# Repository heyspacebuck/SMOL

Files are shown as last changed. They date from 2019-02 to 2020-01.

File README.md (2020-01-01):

# SMOL

## **S**lot-in **M**anipulator of **O**utput **L**evels

## (Revision 7)

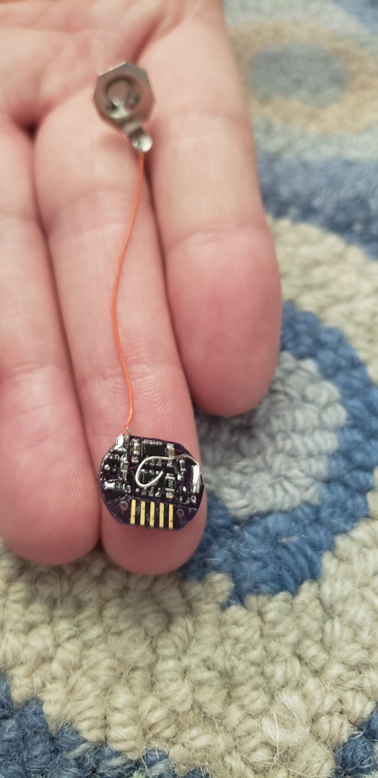
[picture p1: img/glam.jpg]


It's a little PCB to rapidly turn on/off any simple battery-powered circuits. An Atmel ATTiny drives an N-channel MOSFET, which selectively breaks or completes the circuit. The tiny form factor makes it super-simple to install in a battery-powered circuit. Just slot the board between the negative end of the battery and the spring contact, and run a single wire up to the positive battery terminal.

Even with its miniscule form factor, SMOL is designed to be built by surface-mount novices! It has friendly large SMD pads to accept 0603 or 0805 components, and relatively big IC packages (no pitch smaller than 0.90 mm).

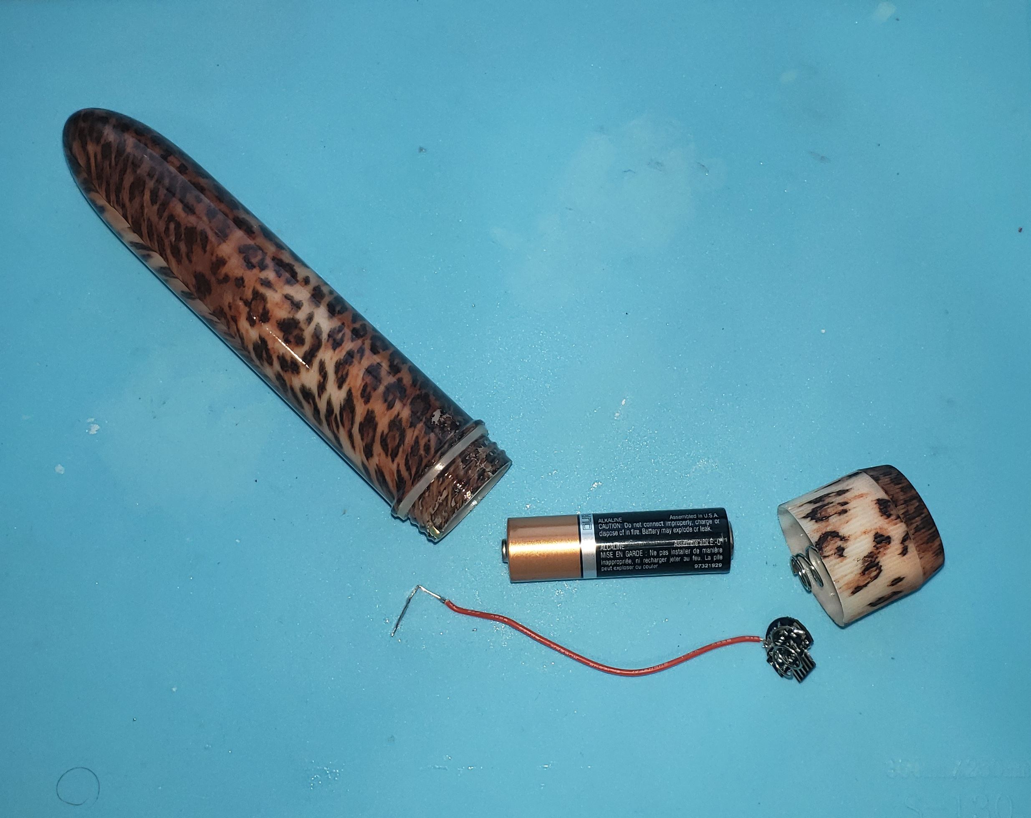
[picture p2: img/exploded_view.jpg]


If you want to contribute, please do! This thing is here for everyone to experiment with! The circuit is designed in KiCad, just clone/download it and open the project. The project includes self-contained parts and footprints libraries, so it *should* work on any KiCad 5 installation.

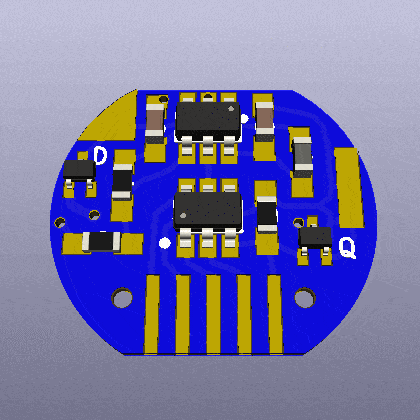
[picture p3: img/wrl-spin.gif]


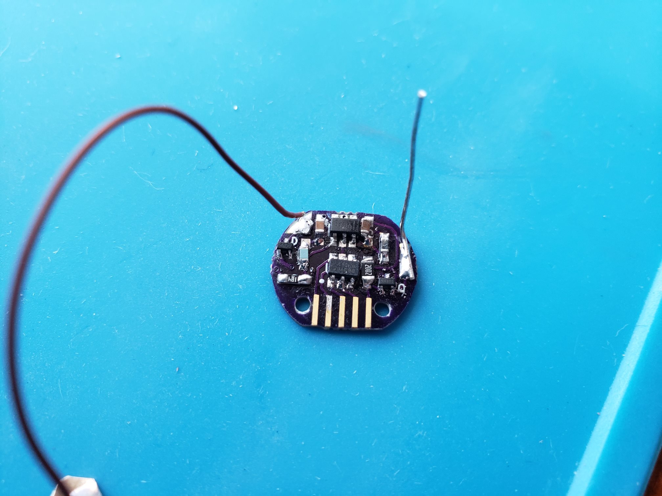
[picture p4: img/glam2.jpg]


## Programming the SMOL
That card-edge connector on the picture above is the [programming interface](programmer.md). Designing this part has been tougher than designing the actual SMOL! But once you get it working, you have the ATTiny10's entire kilobyte of program memory at your disposal. I suggest looking at the [example programs](Code%20examples/readme.md)

## Schematic
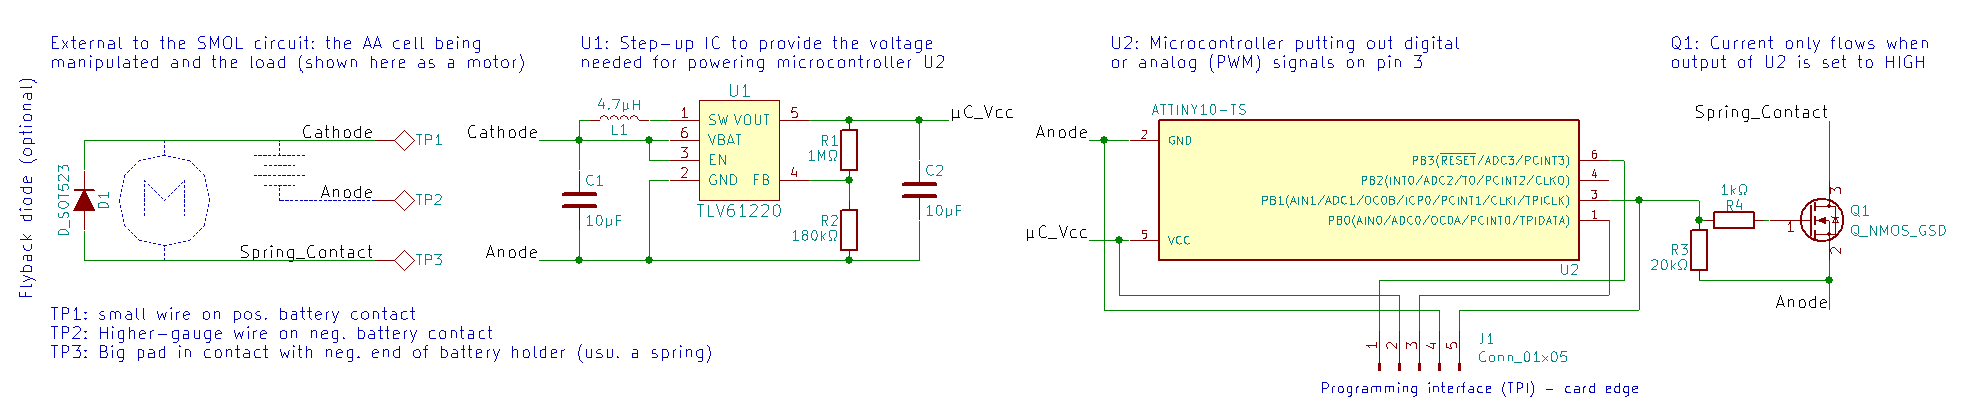
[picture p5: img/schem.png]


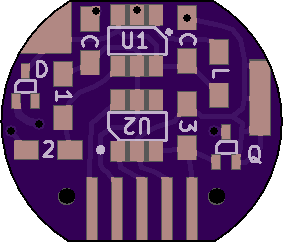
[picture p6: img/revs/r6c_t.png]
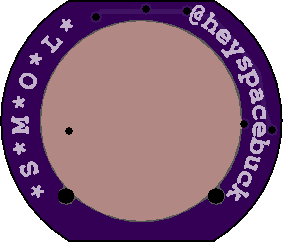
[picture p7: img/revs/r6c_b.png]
 

## Bill of Materials
| Designation | Description | My Source | My Cost (USD) | Notes |
|:---:|---|---|---|---|
| | Printed circuit board | JLCPCB | $0.125 | See the /gerbs/ folder |
| R1 | 1 MΩ resistor, SMD 0603 | [Digikey](https://www.digikey.com/product-detail/en/vishay-beyschlag/MCT06030C1004FP500/MCT0603-1.00M-CFCT-ND/2607877) | $0.180 | Abbreviated to "1" on the silkscreen. |
| R2 | 180 kΩ resistor, SMD 0603 | [Digikey](https://www.digikey.com/product-detail/en/yageo/RC0603FR-07180KL/311-180KHRCT-ND/729942) | $0.015 | Abbreviated to "2" on the silkscreen. |
| R3 | 20 kΩ resistor, SMD 0603  | [Digikey](https://www.digikey.com/product-detail/en/panasonic-electronic-components/ERJ-3EKF2002V/P20.0KHCT-ND/198237) | $0.100 | Abbreviated to "3" on the silkscreen. |
| R4 | 200 Ω resistor, SMD 0603  | [Digikey](https://www.digikey.com/product-detail/en/panasonic-electronic-components/ERJ-3EKF2000V/P200HCT-ND/198240) | $0.100 | Abbreviated to "4" on the silkscreen. |
| C1, C2 | 10 μF capacitor, SMD 0603 | [Digikey](https://www.digikey.com/product-detail/en/murata-electronics-north-america/ZRB18AR61C106ME01L/490-10990-1-ND/5321191) | $0.365 | Both are abbreviated to "C" on the silkscreen. |
| L1 | 4.7 μH inductor, SMD 0603 | [Digikey](https://www.digikey.com/product-detail/en/tdk-corporation/MLF1608A4R7KTA00/445-1021-1-ND/504419) | $0.200 | I should probably use one that's rated to more than 30 mA. Abbreviated to "L" on the silkscreen. |
| Q1 | N-channel MOSFET, SMD SOT-523 | [Digikey](https://www.digikey.com/product-detail/en/diodes-incorporated/DMG1012T-7/DMG1012T-7DICT-ND/2181232) | $0.360 | [Datasheet](https://www.diodes.com/assets/Datasheets/ds31783.pdf). Abbreviated to "Q" on the silkscreen. |
| D1 | General purpose diode, SMD SOT-523 | [Digikey](https://www.digikey.com/product-detail/en/micro-commercial-co/MMBD4448HT-TP/MMBD4448HT-TPMSCT-ND/2041561) | $0.270 | [Datasheet](http://www.mccsemi.com/up_pdf/MMBD4448HT_HTC_HTA_HTS%28SOT-523%29.pdf). This part is optional but protects the board from motor back-EMF. Abbreviated to "D" on the silkscreen. |
| U1 | TLV61220 DC-DC boost converter, SMD SOT-23-6 | [Digikey](https://www.digikey.com/product-detail/en/texas-instruments/TLV61220DBVR/296-30547-1-ND/3458120) | $0.900 | [Datasheet](http://www.ti.com/lit/ds/symlink/tlv61220.pdf) |
| U2 | ATTiny10 8-bit microcontroller, SMD SOT-23-6 Narrow | [Digikey](https://www.digikey.com/product-detail/en/microchip-technology/ATTINY10-TSHR/ATTINY10-TSHRCT-ND/2136158) | $0.340 | [Datasheet](http://ww1.microchip.com/downloads/en/DeviceDoc/Atmel-8127-AVR-8-bit-Microcontroller-ATtiny4-ATtiny5-ATtiny9-ATtiny10_Datasheet.pdf). Uses the TPI programming interface, which is a pain. |
| | Approx. 5 cm of 30AWG wire | Anywhere | $0.000 | Solder to TP1 and attach the other end to the battery's positive terminal. Soldering an old battery clip to the end helps make a reliable connection. |
| | Approx. 1 cm of stiff bare wire | Anywhere | $0.000 | Solder to TP2 and bend so the battery's negative terminal rests on it but doesn't short any traces. |
| | Conformal coating (or other insulating material) | Anywhere | $0.000 | Optional but recommended. Insulate the board so the stiff bare wire can't short anything. |

TOTAL COST PER BOARD: approx. $3.50

## Revision history
SMOL has changed a lot since I first got the idea. Amazingly, it hasn't gotten bigger. [For a commentated revision history: click here.](revisions.md)

## Contact info:
- E-mail heyspacebuck at gmail
- Twitter @heyspacebuck
- Telegram @spacebuck

## To Do:
- Write better assembly instructions
- Add pictures + video
- Post sample AVR code
- Add OSHW certification mark

------

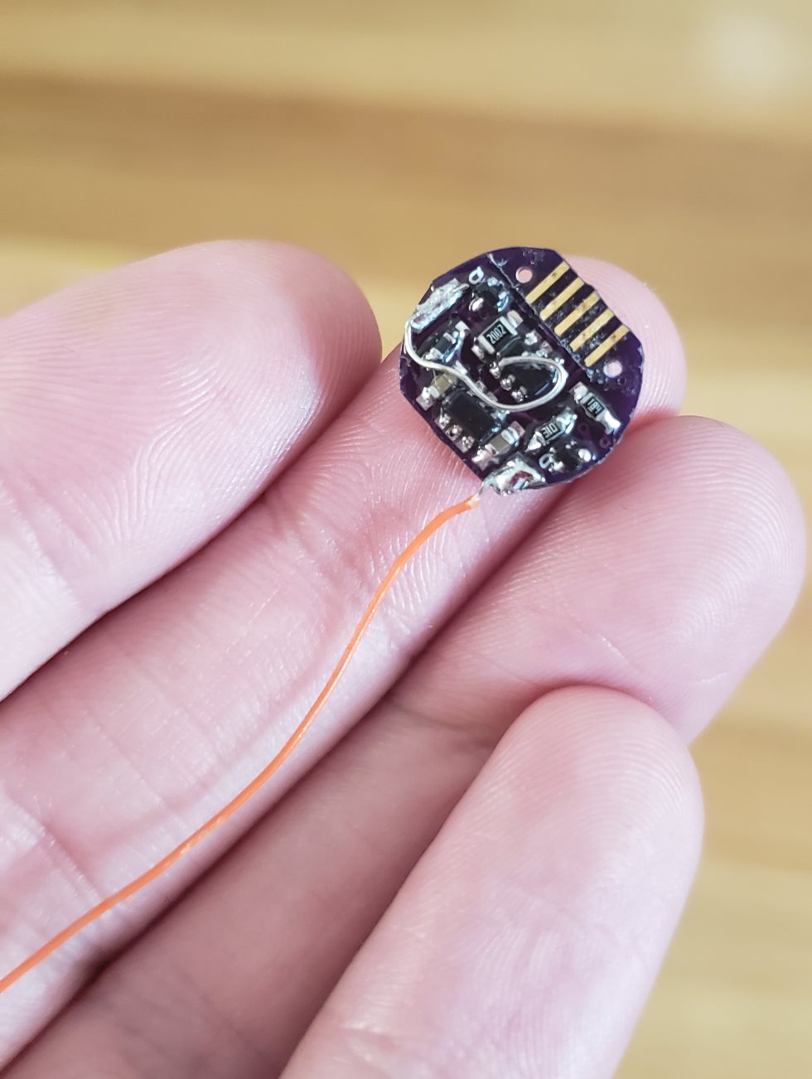
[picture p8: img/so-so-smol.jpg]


IT'S SO SMOL

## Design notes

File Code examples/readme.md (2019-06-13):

# Example AVR programs

I'm working on this section! The documentation is either flawed or absent altogether.

## 1. LED PWM pulse

This example pulses an LED with a PWM frequency of 312.5 Hz. It's overly complicated because it's based on the pomodoro timer, below.

## 2. Vibrator PWM pomodoro timer

The PWM rate in the previous example is 312.5 Hz. The coils of a motor would soak that up like a sponge! We need a faster PWM frequency if we're driving a motor, so that's what this example does.

## 3. Pseudorandom number generator

The ATTiny10 and ATTiny5 have an ADC which we can connect to PB0 (Pin 1, which on SMOL isn't connected to anything). By reading the least significant bit of the 8-bit analog reading, we get a fairly random result from environmental noise! Right now I'm just using this to set the motor on or off at one-second intervals.

## 4. Morse code "I Love You"

"If I had a little telegraph tapping in my brain / It would tap out Morse code 'I Love You'" --Devo, "The Words Get Stuck In My Throat" (Okay, so it's a cover of a song from _War of the Gargantuas_ but I only know it because of Booji Boy)

The Morse alphabet (A-Z, no numbers or punctuation yet) is included in `MorseAlphabet.cpp`. Simply change the functions called in the main .cpp file and you could spell out whatever you want!

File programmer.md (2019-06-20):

# Tiny Programming Interface (TPI) programmers for SMOL

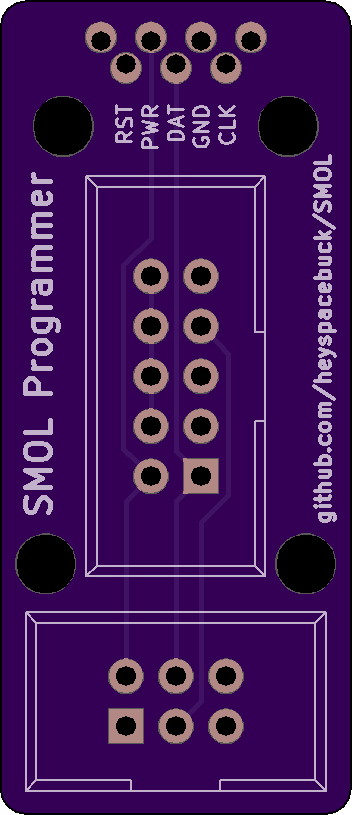
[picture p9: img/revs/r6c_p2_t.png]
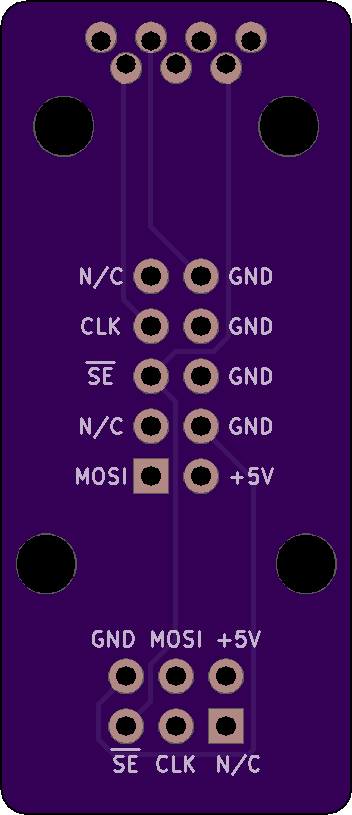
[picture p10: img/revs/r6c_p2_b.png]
 <br>
This design works with USBasp or a breadboard if you are using [this programming approach](http://www.technoblogy.com/show?1YQY).

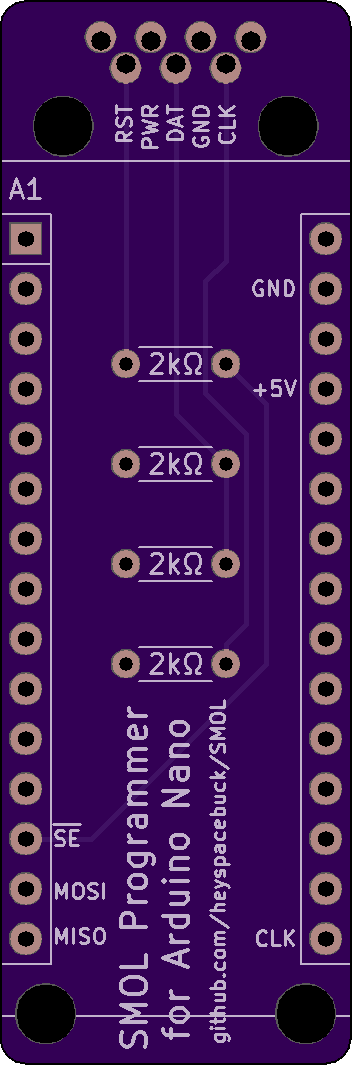
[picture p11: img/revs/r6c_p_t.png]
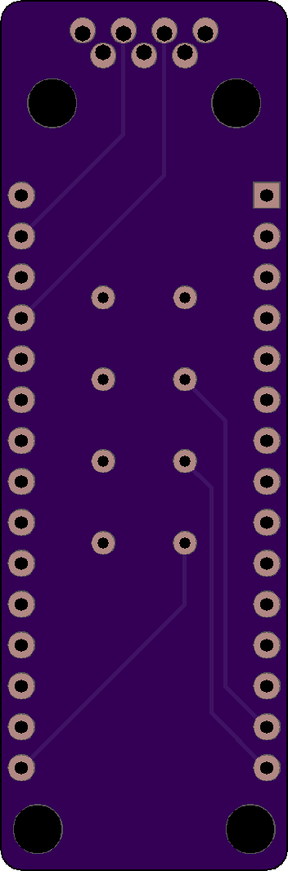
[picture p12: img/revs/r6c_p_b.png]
 <br>
This design works with the Arduino Nano (or breadboard) if you are using [this programming approach](http://junkplusarduino.blogspot.com/p/attiny10-resources.html).

The ATTiny10 at the heart of the SMOL can't be programmed like other ATTiny ICs. Instead of the normal 6-wire SPI (Serial Programming Interface) protocol, the ATTiny4/5/9/10 family use the 5-wire TPI (Tiny Programming Interface) protocol. Tutorials on working with TPI are relatively scarce. If you have a [Fischl USBasp](https://www.fischl.de/usbasp/) (or a knockoff that still supports low-clock-speed programming), you can write and upload your AVR program within the Arduino IDE by [following this landmark tutorial by Johnson Davies](http://www.technoblogy.com/show?1YQY). If you don't have USBasp, you can still upload compiled programs using this [very clever, very janky Arduino sketch](http://junkplusarduino.blogspot.com/p/attiny10-resources.html). Atmel Studio *should* work as an IDE but I haven't had any luck yet—contact me if you figure it out!

No matter what software you use, you'll need some additional hardware to connect your SMOL and your computer. On SMOL revision 7, the five TPI signals are routed to the five copper fingers, with a 50 mil (1.27 mm) pitch. There is a pair of non-plated through-holes (NPTH) to help align the programmer and the SMOL fingers.

## The least-bad programmer thus far

I'm using the classic [spring-loaded pogo pin](https://www.adafruit.com/product/2430) to make a reliable electrical connection between boards. These can be bought in bulk from lots of places—just make sure to get ones that are approx. 1mm diameter at their widest point.

The programmer has space for seven pogo pins: five signals and two alignment pins. The alignment pins should slide nicely into the 0.8mm diameter non-plated holes on SMOL, thereby forcing the five signal pins to accurately align themselves. The seven pogo pins are soldered into the programmer; be very careful on this step!

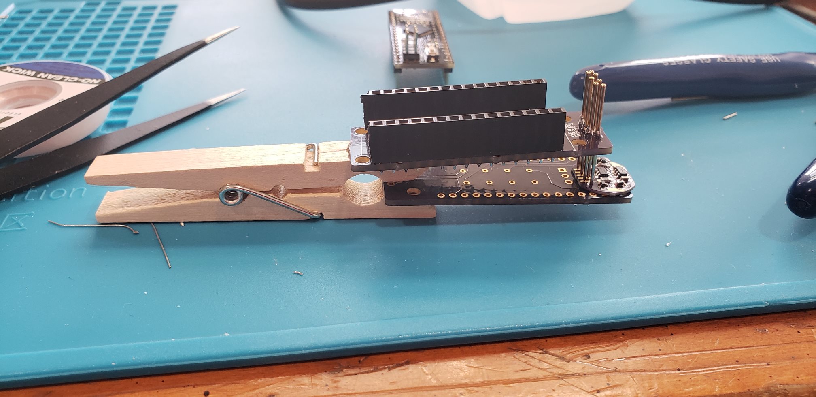
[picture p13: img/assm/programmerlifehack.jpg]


## Other attempts at SMOL programmers

My first programmers were wires soldered to bare pads. After that I tried programmers with mating fingers slid against the SMOL. This worked alright, but requires a lot of force to keep the programmer pressed against the SMOL, which started to take a toll on my poor fingertips:

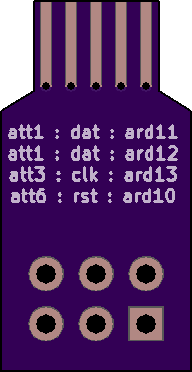
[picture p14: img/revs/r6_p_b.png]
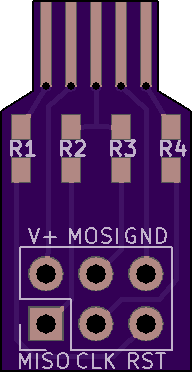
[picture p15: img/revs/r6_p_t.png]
 

In an attempt to work smarter, not harder, I made this sandwich programmer, which doesn't work well but is still my favorite design:

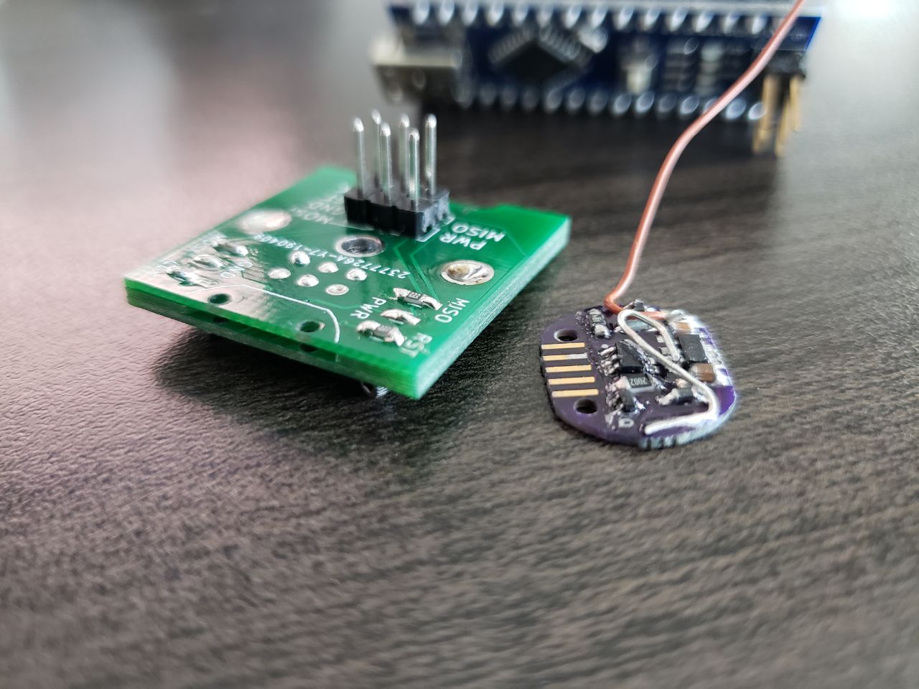
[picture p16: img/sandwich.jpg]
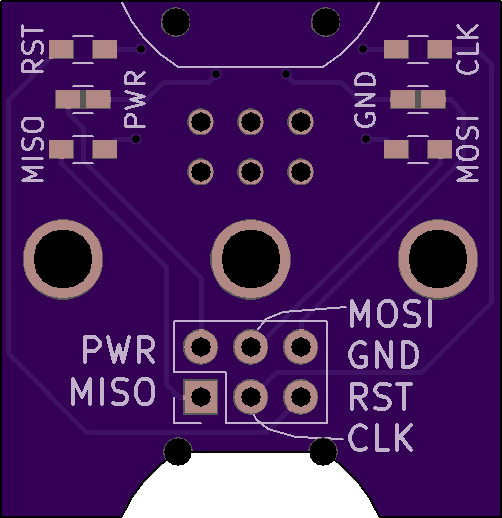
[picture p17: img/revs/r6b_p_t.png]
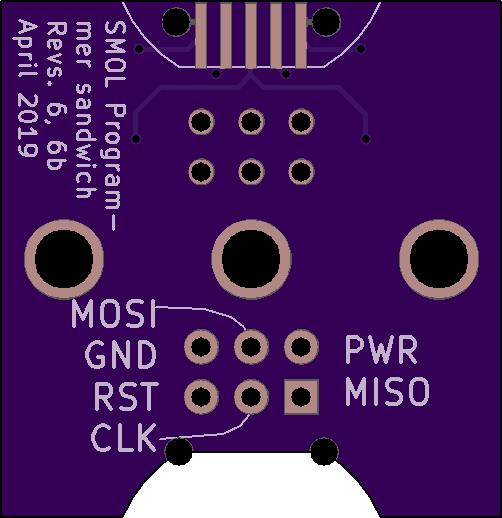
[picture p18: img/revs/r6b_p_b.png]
  

The middle PCB has a cutout to perfectly line up the SMOL, the top one has mating fingers, and the bottom one...well, I shouldn't have used a bottom PCB; I should have used some sort of spring apparatus to press the SMOL against the top fingers. In the 3-layer sandwich design, there's enough play that this programmer only works about 5% of the time. I still think this approach shows promise, but I can't figure out an economical way to make or buy card-edge receptacles for five fingers at 0.050" pitch.

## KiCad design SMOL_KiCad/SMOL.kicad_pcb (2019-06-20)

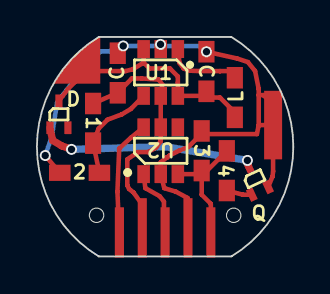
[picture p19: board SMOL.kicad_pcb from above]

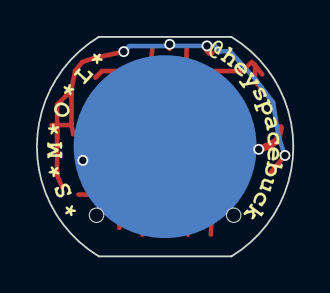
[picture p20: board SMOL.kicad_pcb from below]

Board: 2 copper layers, 14.2 x 12.2 mm, 19 parts (3 on the bottom side), 10 nets.

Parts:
1: 1MΩ; 0603_HandSoldering
2: 180kΩ; 0603_HandSoldering
3: 20kΩ; 0603_HandSoldering
4: 1kΩ; 0603_HandSoldering
C: 10μF; 0603_HandSoldering
C#2: 10μF; 0603_HandSoldering
D: D_SOT523; SOT523_HandSoldering
GFX1: credits2-name
GFX2: credits2-title
HOLE1, HOLE2: SolderWirePad_single_2mmDrill
J1: Conn_01x05; edgeconn
L: 4.7μH; 0603_HandSoldering
Q: Q_NMOS_GSD; SOT523_HandSoldering
TP1: TEST; Anchor_Pad
TP2: TEST; SPRING_ANCHOR
TP3: TEST; SPRING_LANDING
U1: TLV61220; SuperSOT-6
U2: ATTINY10-TS; SuperSOT-6

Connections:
/Anode: 2.2, 3.1, C.2, C#2.2, J1.4, Q.2, TP2.1, U1.2, U2.2
/Cathode: C.1, D.3, L.1, TP1.1, U1.3, U1.6
/Spring_Contact: D.1, Q.3, TP3.1
/μC_Vcc: 1.1, C#2.1, J1.2, U1.5, U2.5
unnamed: J1.1, U2.6
unnamed: J1.3, U2.1
unnamed: 3.2, 4.1, J1.5, U2.3
unnamed: L.2, U1.1
unnamed: 4.2, Q.1
unnamed: 1.2, 2.1, U1.4

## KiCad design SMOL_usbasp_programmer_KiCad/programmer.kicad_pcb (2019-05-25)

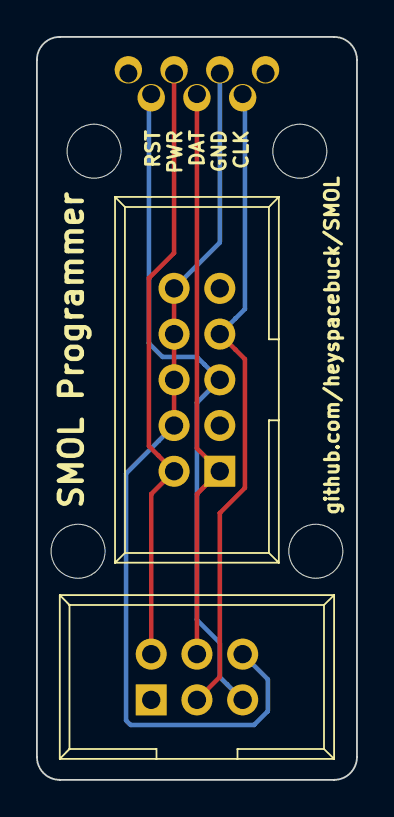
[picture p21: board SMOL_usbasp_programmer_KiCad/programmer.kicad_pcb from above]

Board: 2 copper layers, 17.8 x 41.3 mm, 9 parts (0 on the bottom side), 5 nets.

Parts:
CON1: AVR-TPI-6; IDC_Header_Straight_6pins
CON2: AVR-ISP-10; IDC_Header_Straight_10pins
HOLE1, HOLE2, HOLE3, HOLE4: MountingHole_3.2mm_M3
HOLE5, HOLE6: SolderWirePad_single_1mmDrill
J2: Conn_01x05; edgeconn

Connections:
/att_clk: CON1.3, CON2.7, J2.5
/att_data: CON1.4, CON2.1, J2.3
/att_reset: CON1.5, CON2.5, J2.1
/pwr: CON1.2, CON2.2, J2.2
GNDREF: CON1.6, CON2.4, CON2.6, CON2.8, CON2.10, J2.4

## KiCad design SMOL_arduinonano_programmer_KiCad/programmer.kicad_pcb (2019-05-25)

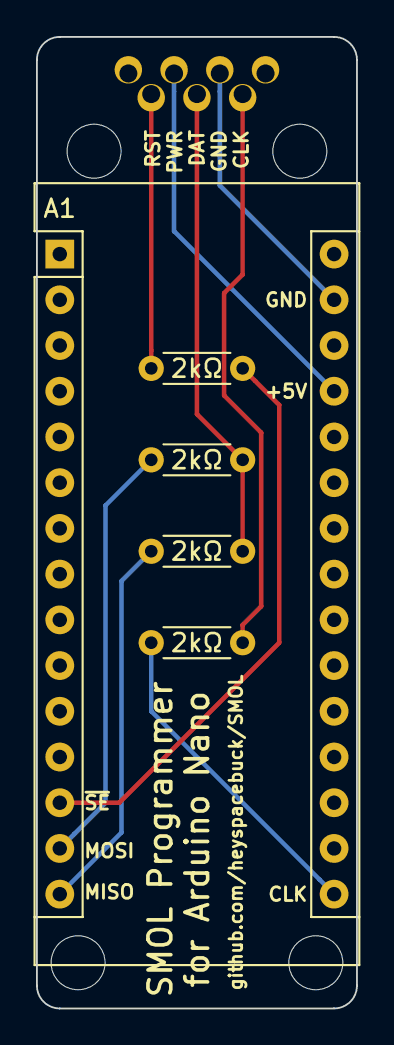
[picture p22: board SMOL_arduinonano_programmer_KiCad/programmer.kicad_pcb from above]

Board: 2 copper layers, 17.8 x 54.0 mm, 12 parts (0 on the bottom side), 9 nets.

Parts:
2kΩ, 2kΩ#2, 2kΩ#3, 2kΩ#4: 2k; R_Axial_DIN0204_L3.6mm_D1.6mm_P5.08mm_Horizontal
A1: Arduino_Nano_v3.x; Arduino_Nano
HOLE1, HOLE2, HOLE3, HOLE4: MountingHole_3.2mm_M3
HOLE5, HOLE6: SolderWirePad_single_1mmDrill
J2: Conn_01x05; edgeconn

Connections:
/att_clk: 2kΩ#4.2, J2.5
/att_data: 2kΩ#2.2, 2kΩ#3.2, J2.3
/att_reset: 2kΩ.2, J2.1
/prog_clk: 2kΩ#4.1, A1.16
/prog_miso: 2kΩ#2.1, A1.14
/prog_mosi: 2kΩ#3.1, A1.15
/prog_reset: 2kΩ.1, A1.13
/pwr: A1.27, J2.2
GNDREF: A1.4, A1.29, J2.4

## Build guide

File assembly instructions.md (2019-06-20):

# SMOL assembly instructions

Instructions are coming soon!

## Bill of Materials
| Designation | Description | My Source | My Cost (USD) | Notes |
|:---:|---|---|---|---|
| | Printed circuit board | JLCPCB | $0.125 | See the /gerbs/ folder |
| R1 | 1 MΩ resistor, SMD 0603 | [Digikey](https://www.digikey.com/product-detail/en/vishay-beyschlag/MCT06030C1004FP500/MCT0603-1.00M-CFCT-ND/2607877) | $0.180 | Abbreviated to "1" on the silkscreen. |
| R2 | 180 kΩ resistor, SMD 0603 | [Digikey](https://www.digikey.com/product-detail/en/yageo/RC0603FR-07180KL/311-180KHRCT-ND/729942) | $0.015 | Abbreviated to "2" on the silkscreen. |
| R3 | 20 kΩ resistor, SMD 0603  | [Digikey](https://www.digikey.com/product-detail/en/panasonic-electronic-components/ERJ-3EKF2002V/P20.0KHCT-ND/198237) | $0.100 | Abbreviated to "3" on the silkscreen. |
| R4 | 200 Ω resistor, SMD 0603  | [Digikey](https://www.digikey.com/product-detail/en/panasonic-electronic-components/ERJ-3EKF2000V/P200HCT-ND/198240) | $0.100 | Abbreviated to "4" on the silkscreen. |
| C1, C2 | 10 μF capacitor, SMD 0603 | [Digikey](https://www.digikey.com/product-detail/en/murata-electronics-north-america/ZRB18AR61C106ME01L/490-10990-1-ND/5321191) | $0.365 | Both are abbreviated to "C" on the silkscreen. |
| L1 | 4.7 μH inductor, SMD 0603 | [Digikey](https://www.digikey.com/product-detail/en/tdk-corporation/MLF1608A4R7KTA00/445-1021-1-ND/504419) | $0.200 | I should probably use one that's rated to more than 30 mA. Abbreviated to "L" on the silkscreen. |
| Q1 | N-channel MOSFET, SMD SOT-523 | [Digikey](https://www.digikey.com/product-detail/en/diodes-incorporated/DMG1012T-7/DMG1012T-7DICT-ND/2181232) | $0.360 | [Datasheet](https://www.diodes.com/assets/Datasheets/ds31783.pdf). Abbreviated to "Q" on the silkscreen. |
| D1 | General purpose diode, SMD SOT-523 | [Digikey](https://www.digikey.com/product-detail/en/micro-commercial-co/MMBD4448HT-TP/MMBD4448HT-TPMSCT-ND/2041561) | $0.270 | [Datasheet](http://www.mccsemi.com/up_pdf/MMBD4448HT_HTC_HTA_HTS%28SOT-523%29.pdf). This part is optional but protects the board from motor back-EMF. Abbreviated to "D" on the silkscreen. |
| U1 | TLV61220 DC-DC boost converter, SMD SOT-23-6 | [Digikey](https://www.digikey.com/product-detail/en/texas-instruments/TLV61220DBVR/296-30547-1-ND/3458120) | $0.900 | [Datasheet](http://www.ti.com/lit/ds/symlink/tlv61220.pdf) |
| U2 | ATTiny10 8-bit microcontroller, SMD SOT-23-6 Narrow | [Digikey](https://www.digikey.com/product-detail/en/microchip-technology/ATTINY10-TSHR/ATTINY10-TSHRCT-ND/2136158) | $0.340 | [Datasheet](http://ww1.microchip.com/downloads/en/DeviceDoc/Atmel-8127-AVR-8-bit-Microcontroller-ATtiny4-ATtiny5-ATtiny9-ATtiny10_Datasheet.pdf). Uses the TPI programming interface, which is a pain. |
| | Approx. 5 cm of 30AWG wire | Anywhere | $0.000 | Solder to TP1 and attach the other end to the battery's positive terminal. Soldering an old battery clip to the end helps make a reliable connection. |
| | Approx. 1 cm of stiff bare wire | Anywhere | $0.000 | Solder to TP2 and bend so the battery's negative terminal rests on it but doesn't short any traces. |
| | Conformal coating (or other insulating material) | Anywhere | $0.000 | Optional but recommended. Insulate the board so the stiff bare wire can't short anything. |

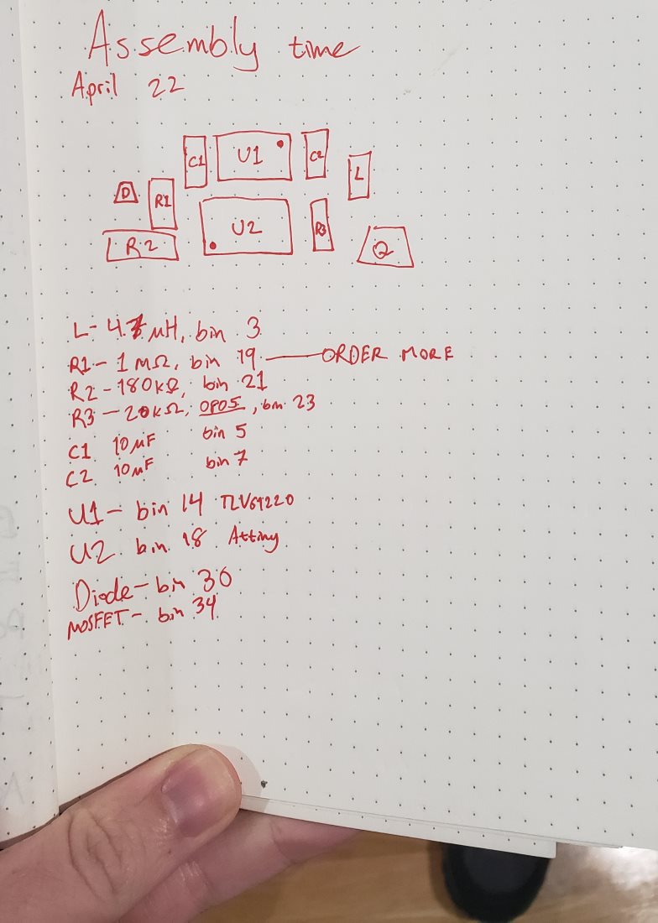
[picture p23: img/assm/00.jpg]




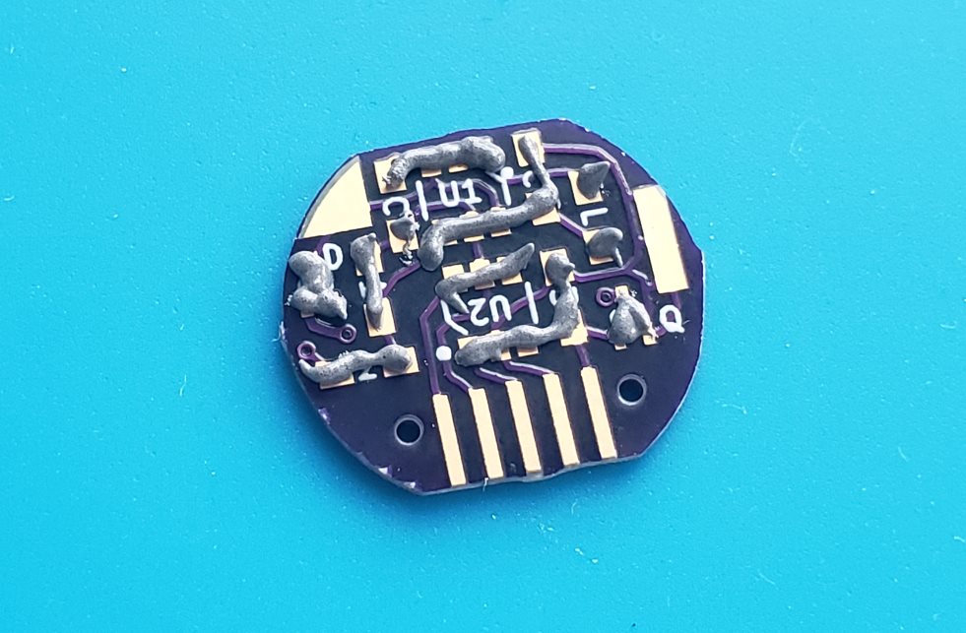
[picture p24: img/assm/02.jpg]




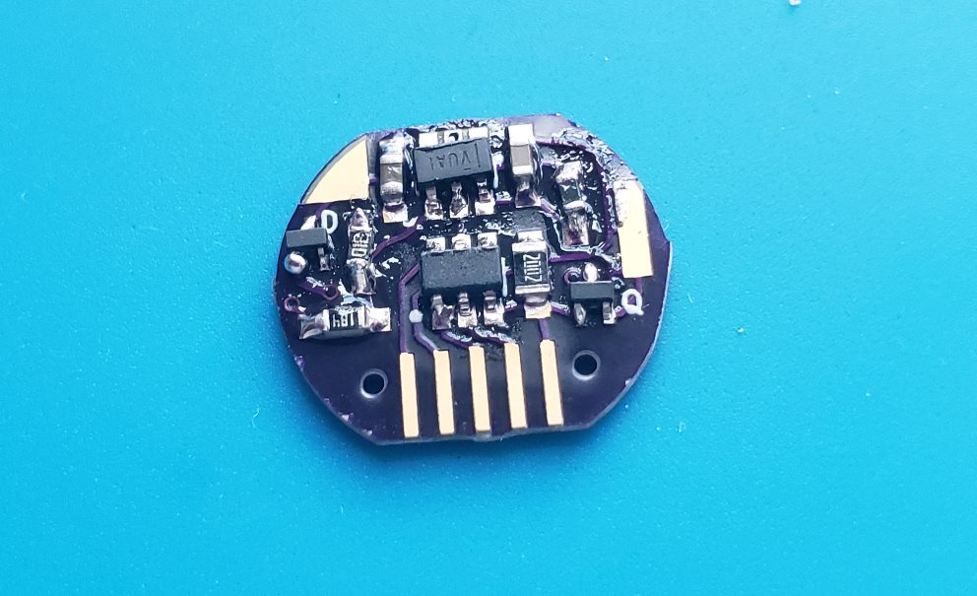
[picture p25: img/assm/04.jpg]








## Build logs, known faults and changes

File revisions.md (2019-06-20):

# SMOL Revision history

## Revision 7
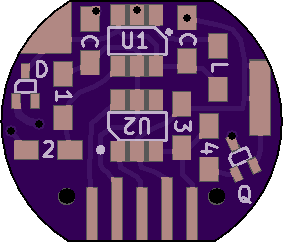
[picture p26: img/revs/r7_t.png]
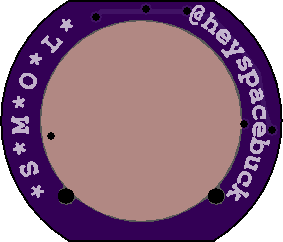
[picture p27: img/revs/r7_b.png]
 

After thinking I'd finalized the hardware, I began running into weird MOSFET behavior. A helpful fur pointed out that I needed a small resistor between the MOSFET gate and microcontroller. So, here we are, final revision take 2. The [programmers](programmer.md) are the same as revision 6b.

## Revision 6b
 

This was intended to be the final hardware revision. I called it "6b" instead of "7" because it's made up of lesser revisions--the component layout is the same as revision 6, but I changed the routing and board outline. In addition I introduced some [programmers](programmer.md) that work more reliably.

## Revision 6
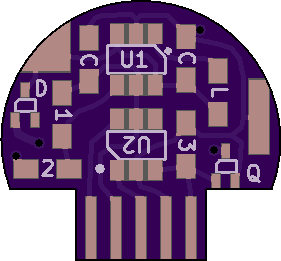
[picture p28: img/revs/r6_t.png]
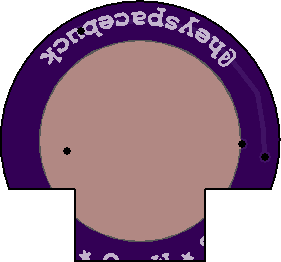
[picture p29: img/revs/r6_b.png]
 

I was super happy with using and programming this version, but it *does* look like a skull. The form factor is not cute enough!

## Revision 5
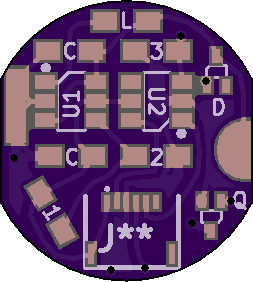
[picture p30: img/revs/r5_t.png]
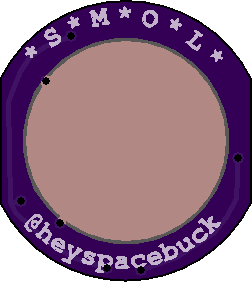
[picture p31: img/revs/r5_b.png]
 

Before trying the card-edge-type teeth of revision 6, I tried using a suuuuper tiny FFC connector to link the board to a programmer. This *could* work, but the part is fragile and not as hand-solderable as the other components.

## Revision 4
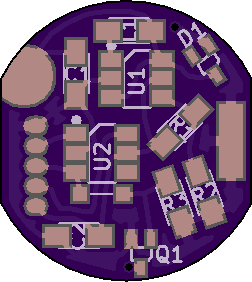
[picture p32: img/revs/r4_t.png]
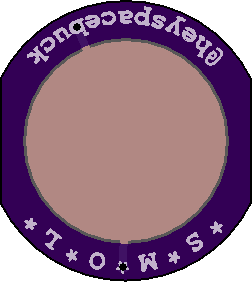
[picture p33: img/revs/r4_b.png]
 

I think this was the first version I was happy enough to show off to people. Programming/reprogramming still involved soldering wires to the five oval pads on the left. I needed a jumper beneath U2 to finish routing the design, but I still quite like it. It still looks good, to me.

## Revision 3
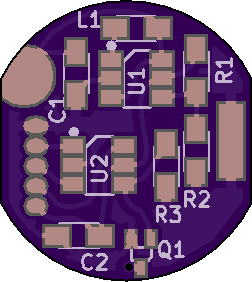
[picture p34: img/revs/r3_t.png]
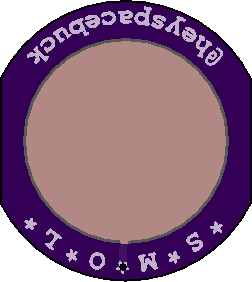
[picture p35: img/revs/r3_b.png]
 

This was the first version to use a SOT-23 microcontroller instead of an SOIC-8 microcontroller. No diode to protect against back EMF. Programmable by soldering wires to those five oval pads.

## Revision 2
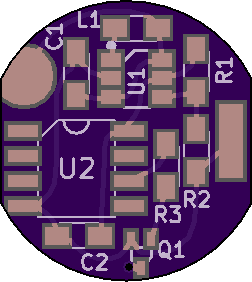
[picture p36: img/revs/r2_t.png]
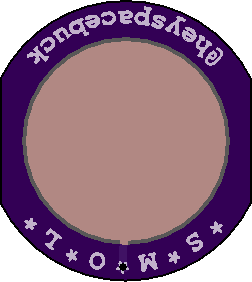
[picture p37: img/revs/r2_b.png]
 

Just another early revision meant for an ATTiny13 or an ATTiny85.

## Revision 1
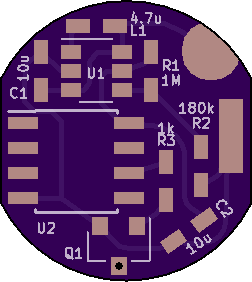
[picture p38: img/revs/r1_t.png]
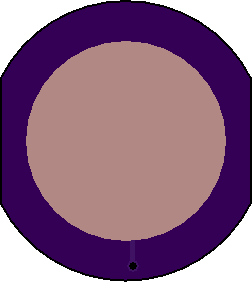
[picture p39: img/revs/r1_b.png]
 

My goodness, I still can't get over how big those SOIC-8 chips look at this scale.

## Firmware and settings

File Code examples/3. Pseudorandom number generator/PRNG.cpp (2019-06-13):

// Analog input test

#include <avr/io.h>
#include <util/delay.h>

int analogReading;
signed int timerCounter = 0;

void Setup(void) {
  // Set registers for flicker and setup
  TCCR0A = (2<<COM0B0) | (1<<WGM01); // Datasheet p100; set PB1 (Pin 3) as PWM pin
  TCCR0B = (2<<CS00) | (3<<WGM02);   // Datasheet p103; set PWM behavior, set clock scaler to 125 kHz
  OCR0B = 0;                         // Counter for PWM on PB1 (pin 3)
  ICR0 = 124;                        // Counter resets every millisecond, good for timing
  OCR0A = 60;                        // A nice middle-of-the-range value for timing during PWM
  DDRB = 1<<PORTB1;                  // Set PB1 (pin 3) as output
  ADMUX = 0b00<<MUX0;                // Set PB0 (pin 1) as analog input
  ADCSRA = 1<<ADEN | 3<<ADPS0;       // Enable ADC | Set ADC clock to 125 kHz
}

void OCR0A_idle(void) {
  // Idle until compare match occurs
  while(!(TIFR0 & (1<<OCF0A)));
  
  // Clear interrupt flag by writing a 1 to the register
  TIFR0 |= 1<<OCF0A;
}

void idle(int cycles) {
  timerCounter = 0;
  while (timerCounter < cycles) {
    OCR0A_idle();
    timerCounter++;
  }
}

int getEntropy(int bits) {
  int entropy = 0;
  for (int bit = 0; bit<bits; bit++) {
    // Trigger ADC collection
    ADCSRA = ADCSRA | 1<<ADSC;
    // Wait for ADC conversion to finish
    while (ADCSRA & 1<<ADSC) {
      ;
    }
    // Write LSB of ADC to entropy byte
    if (ADCL & 1) {
      entropy |= _BV(bit);
    }
    _delay_us(20);
  }
  return(entropy);
}


int main(void) {
  
  // Start timer
  Setup();

  while(1) {
    // Collect one bit of entropy
    int rando = getEntropy(1);
    // If bit is 1, turn motor on; else, turn motor off
    if (rando & 1) {
      OCR0B = 125;
    } else {
      OCR0B = 0;
    }
    // Wait one second
    idle(1000);
  }
}

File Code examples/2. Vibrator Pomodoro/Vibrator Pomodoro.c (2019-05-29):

// TEENY TINY PWMODORO
// Idle for 25 minutes; gently pulse a motor on PB1 for five minutes; repeat

#define F_CPU 1000000
#include <avr/io.h>
#include <util/delay.h>

void SetIdleMode(void) {
  // Set registers for the "idle phase" (do nothing for 25 minutes)
  TCCR0B = 3<<CS00;           // Counter prescaler 1:64, that's 15625 cps
  TCNT0 = 0;                  // Counter starts at 0
  OCR0A = F_CPU / 64 - 1;     // One second's worth of cycles (Should I be using OCR0A or OCR0B? Does it matter?)
  TCCR0A &= 0b00001100;       // Reset all the resettable values in TCCROA register
  OCR0B = 0;
}

void SetActiveMode(void) {
  // Set timer to fast PWM with max value of ICR0 (mode 14 in datasheet p102)
  TCCR0A = (1<<COM0B1) | (1<<WGM01); // Datasheet p100
  TCCR0B = (2<<CS00) | (3<<WGM02);   // Datasheet p103
  OCR0B = 0;                         // Counter for PWM on PB1 (pin 3)
  ICR0 = 49;                         // Gives a PWM freq. of 125000/50 = 2500 Hz, good for driving a motor of this size (I think)
  OCR0A = 25;                        // A nice middle-of-the-range value for timing during PWM
}

void OCR0A_idle(void) {
  // Idle until compare match occurs
  while(!(TIFR0 & (1<<OCF0A)));
  
  // Clear interrupt flag by writing a 1 to the register
  TIFR0 |= 1<<OCF0A;
}

int main(void) {
  
  signed int idlecounter = 9999;
  signed int activecounter1 = 149;
  signed int activecounter2 = 0;
  signed int i, j;
  
  // Start timer
  SetIdleMode();
  
  // Set PB1 (pin 3 on ATTiny10) as output
  DDRB = 1<<PORTB1;
  
  while(1) {
    // Increment counter variable
    idlecounter++;
    // Add 1 second to counter
    OCR0A += F_CPU / 64;
    
    OCR0A_idle();
    
    // If counter above our time limit (25 minutes), enter Active Mode for five-ish minutes (how can I make this more precise?)
    if (idlecounter >= 1250) { // Make this a lot shorter when debugging
      SetActiveMode();
      activecounter2 = 0;
      
      // Sample Active Mode program: pulse up and down
      while(activecounter1 < 150) { // Make this a lot shorter when debugging
        
        OCR0A_idle();
        activecounter2++;
        
        if (activecounter2 <= 2500) {
          OCR0B = 50*activecounter2/2500;
          } else if (activecounter2 < 5000) {
          OCR0B = 50*(5000-activecounter2)/2500;
          } else {
          activecounter1++;
          activecounter2 = 0;
        }
        
      }
      
      // Once Active Mode has run for 5 minutes, return to idling for another 25 minutes
      SetIdleMode();
      idlecounter = 0;
      activecounter1 = 0;
    }
  }
}

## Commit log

2018-06-22 Repo created; missing readme
    [SMOL-B.Cu.gbr, SMOL-B.Mask.gbr, SMOL-B.SilkS.gbr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]
2018-06-23 very minor change in schematic; the motor M was asymmetrical
    [SMOL.sch]
2018-06-25 Hacky fix to board outline; fixed Q1's 3d representation
    [SMOL.kicad_pcb]
2018-06-25 Updated gerbers to reflect the edge cuts change (maybe now JLCPCB will accept my order)
    [SMOL-B.Cu.gbr, SMOL-B.Mask.gbr, SMOL-B.SilkS.gbr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]
2018-06-25 Moved KiCad project to its own folder
    [SMOL.kicad_pcb, SMOL.sch]
2018-07-22 Rearranged components, set up for ATTiny10 instead of 13
    [SMOL-B.Cu.gbr, SMOL-B.Mask.gbr, SMOL-B.SilkS.gbr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]
2018-07-22 Oops, put gerbers in the wrong directory
    [SMOL-B.Cu.gbr, SMOL-B.Mask.gbr, SMOL-B.SilkS.gbr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]
2018-07-31 First release of the ATTiny10 version.
    [SMOL.sch]
2018-07-31 Added diode and re-wired output from U2
    [SMOL-B.Cu.gbr, SMOL-B.Mask.gbr, SMOL-B.SilkS.gbr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]
2018-10-17 Updated schematic and libs to KiCad 5.x
    [SMOL.sch]
2018-10-17 Wrapped up(?) update to KiCad 5.0
    [SMOL.kicad_pcb, SMOL.sch]
2018-10-28 Preparing to update PCB and gerbs for next round of development
    [SMOL.sch]
2018-10-31 Revision 5: added an FFC connector for easier programming (at the expense of my commitment to hand-solderability)
    [SMOL-B.Cu.gbr, SMOL-B.Mask.gbr, SMOL-B.SilkS.gbr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]
2018-11-04 Revision 6 - a card-edge connector with a plug-in programmer
    [SMOL-B.Cu.gbr, SMOL-B.Mask.gbr, SMOL-B.SilkS.gbr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]
2018-11-04 schematic update for readme
    [SMOL.sch]
2018-11-09 Tweaked the bottom silkscreen and moved vias to make it legible
    [SMOL.kicad_pcb]
2018-12-21 Updated gerbs, added folder for AVR programs
    [SMOL.kicad_pcb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]
2019-02-26 Working toward new release, updating images and documents
    [SMOL.kicad_pcb]
2019-02-26 Update spinning render
    [SMOL.kicad_pcb]
2019-03-22 re-jigging the form factor of circuit revision 6
    [SMOL-B.Cu.gbr, SMOL-B.Mask.gbr, SMOL-B.SilkS.gbr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]
2019-03-22 re-sized mounting holes to fit M1.4 bolts, like in japanese watches. Everyone has m1.4 bolts handy, right?
    [SMOL-B.Cu.gbr, SMOL-B.Mask.gbr, SMOL-B.SilkS.gbr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]
2019-04-08 overhauled programmer design; going to try pogo pins and an arduino nano shield
    [programmer-B.Cu.gbr, programmer-B.Mask.gbr, programmer-B.SilkS.gbr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]
2019-04-09 Another variant programmer to test: this one's a sandwich
    [programmer-B.Cu.gbr, programmer-B.Mask.gbr, programmer-B.SilkS.gbr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]
2019-04-27 Revert "Another variant programmer to test: this one's a sandwich"
    This reverts commit 6c5b6402040f09fce85967fa71119872cc965c26.
    [programmer-B.Cu.gbr, programmer-B.Mask.gbr, programmer-B.SilkS.gbr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]
2019-04-27 Reverted the 'sandwich' programmer; tweaked the pogo-pin programmer
    [programmer-B.Cu.gbr, programmer-B.Mask.gbr, programmer-B.SilkS.gbr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]
2019-04-29 Revision 6c - use pogo pins for programming AND alignment
    [SMOL-B.Cu.gbr, SMOL-B.Mask.gbr, SMOL-B.SilkS.gbr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]
2019-05-17 Updating in anticipation of merge
    [programmer-B.Cu.gbr, programmer-B.Mask.gbr, programmer-B.SilkS.gbr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]
2019-05-20 FINALLY fixed the anchor points for mounting holes on SMOL and programmers. Added OSHW logo to library, just in case....
    [SMOL.kicad_pcb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]
2019-05-25 Updated the USBasp programmer; updated programmer silkscreens
    [programmer-B_Cu.gbr, programmer-B_Mask.gbr, programmer-B_SilkS.gbr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]
2019-05-25 Began assembly instructions
2019-05-25 Cleaned up Gerbers, updated programmer images
    [programmer-B.Cu.gbr, programmer-B.Mask.gbr, programmer-B.SilkS.gbr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]
2019-05-25 small cosmetic change to Arduino Nano programmer
    [programmer-B_Cu.gbr, programmer-B_Mask.gbr, programmer-B_SilkS.gbr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]
2019-06-20 Revision seven! Added a small resistor to protect the MOSFET.
    [SMOL.kicad_pcb, SMOL.sch]
2019-06-20 Revision 7 gerbers
    [SMOL-B_Cu.gbr, SMOL-B_Mask.gbr, SMOL-B_SilkS.gbr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]
2019-06-20 Update BOM
